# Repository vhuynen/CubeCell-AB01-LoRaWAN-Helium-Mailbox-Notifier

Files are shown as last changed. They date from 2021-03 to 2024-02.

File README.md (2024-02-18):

# HelTec-Cube-LoRaWAN-Helium-Mailbox-Notifier

The Mailbox Notifier is an IoT DIY project which notifies you each time you received a package or a letter in your letterbox. This is the same projet as the [ESP32-CAM-Mailbox-Notifier](https://github.com/vhuynen/ESP32-CAM-Mailbox-Notifier) one, but designed for long range distance.

This project uses an **HelTec AB01** LoRaWAN module to send data over an LoRaWAN Gateway when WiFi is out of range. I use an [Helium Gateway](https://www.helium.com/) from the **People's Network** in order to forward packets over Helium Network which sends data to [AWS IoT Core](https://aws.amazon.com/iot-core/) (MQTT) or [Pipedream](https://pipedream.com/) (HTTP) etc... LoRaWAN is a bidirectional protocol useful when you need to send few data over long distance (several miles) from low-power and low-bandwidth IoT.

The compromise over this kind of system is that you can't send heavy payload as you are able to do over WiFi. Finally the data must be treated over third-part system.

## Table of Contents

- [HelTec-Cube-LoRaWAN-Helium-Mailbox-Notifier](#heltec-cube-lorawan-helium-mailbox-notifier)
	- [Table of Contents](#table-of-contents)
	- [Architecture Schema](#architecture-schema)
	- [Helium Organization](#helium-organization)
		- [Registering the device in the blockchain](#registering-the-device-in-the-blockchain)
		- [Setting the AWS IoT Core Integration](#setting-the-aws-iot-core-integration)
		- [Decoder Function](#decoder-function)
		- [Flows](#flows)
	- [Telegram API](#telegram-api)
	- [Amazon Web Services](#amazon-web-services)
		- [AWS IoT Core](#aws-iot-core)
		- [Telegram Lambda Function](#telegram-lambda-function)
		- [Twilio Lambda Function](#twilio-lambda-function)
		- [Amazon SNS - Simple Notification Service](#amazon-sns---simple-notification-service)
		- [Rules](#rules)
	- [Heltec AB01](#heltec-ab01)
		- [Prerequisite](#prerequisite)
		- [Data Format](#data-format)
		- [First Byte values](#first-byte-values)
		- [Second and Third Byte](#second-and-third-byte)
		- [Power up](#power-up)
		- [Fetch mail](#fetch-mail)
		- [You have got mail](#you-have-got-mail)
		- [Power-Saving](#power-saving)
	- [Notifications in action](#notifications-in-action)
	- [Electic Schema](#electic-schema)

## Architecture Schema

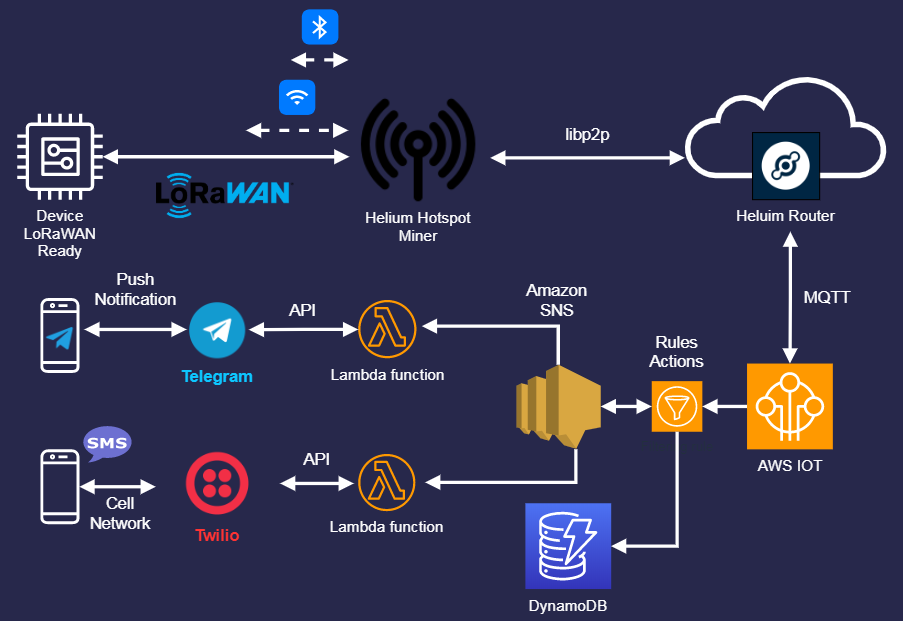
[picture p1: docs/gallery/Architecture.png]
architecture


## Helium Organization

Before going further, you should verify that you are within the coverage of the [Helium Network](https://explorer.helium.com/). Your device should be at the proximity of a least one gateway (350 meters). If not, this allows you to expand the network with your own gateway. After that, you will have to create an account on the [Helium Console](https://console.helium.com/).

### Registering the device in the blockchain

You must register your [device](https://docs.helium.com/use-the-network/console/adding-devices) in the blockchain. This operation can take a while (20 mins) before your device can join the network.
The registration generates three important values that you will have to report in the device's program later.

- **Device EUI** :
  - The DevEUI is a 64-bit globally-unique Extended Unique Identifier (EUI-64) generated throught the Helium Console. This identifier is mandatory because the Helium router has an XOR filter that filters packets from devices it knows only.
- **App EUI** :
  - the AppEUI is an application identifier, and this can be public without any concerns
- **App Key** :
  - The App Key is an AES-128 secret key that is shared between the device and your Helium Organization. This Key is used to provide end-to-end symmetric encryption of your payload data.

### Setting the AWS IoT Core Integration

Helium Console offers more than fifteen integrations and the list is constantly growing.
As expected in the architecture the payload data is forwarded to your AWS Organization. [You will have to connect your Helium Organization to your AWS Organization](https://docs.helium.com/use-the-network/console/integrations/aws-iot-core/).
In my case, the Uplink messages from Helium are published into a Topic named **topic/gateway**

### Decoder Function

[Function Decoder](https://docs.helium.com/use-the-network/console/functions/) is a JavaScript function that allows you to decode the byte payload into a readable JSON Format. The decoded payload is added to the main JSON payload that is forwarded to your Integration target. The payload will be entirely formatted into a [specific function](https://github.com/vhuynen/HelTec-AB01-LoRaWAN-Helium-Mailbox-Notifier/blob/main/source/decoder/MailboxNotifierDecoder.js) that transcodes the mailbox's state (which is hexadecimal) into a readable message enriched by the battery voltage and battery level.

``` js
function Decoder(bytes, port, uplink_info) {

	//decode message type form payload
	var data = bytes[0];
	//output decoded message depending on the data
	switch (data) {
		case 0x03:
			return {
				msg: "Uplink n°" + uplink_info.fcnt + "\n[OK] You have got mail !\nBattery Voltage: "
					+ ((bytes[1] << 8) + bytes[2]) / 1000
					+ " Volts\nBattery Level: "
					+ ((((((bytes[1] << 8) + bytes[2]) / 1000) - 3.7) / (4.2 - 3.7)) * 100).toPrecision(4)
					+ "%\nHave a nice day !",
					code : 03
			};
		case 0x02:
			return {
				msg: "Uplink n°" + uplink_info.fcnt + "\n[OK] You have got maybe a package !\nBattery Voltage: "
					+ ((bytes[1] << 8) + bytes[2]) / 1000
					+ " Volts\nBattery Level: "
					+ ((((((bytes[1] << 8) + bytes[2]) / 1000) - 3.7) / (4.2 - 3.7)) * 100).toPrecision(4)
					+ "%\nHave a nice day !",
			};
		case 0x04:
			return {
				msg: "[ERROR] Doors have been opened for too long since you have powered the device on."
					+ "\nReboot the device to reinitialize it !",
			};
		case 0x05:
			return {
				msg: "[ERROR] Doors have been opened for too long since you have fetched your mail."
					+ "\nReboot the device to re-initialize it !",
			};
		case 0x06:
			return {
				msg: "[ERROR] Doors have been opened for too long by the postman."
					+ "\nReboot the device to reinitialize it !",
			};
		case 0x01:
			return {
				msg: "Uplink n°" + uplink_info.fcnt + "\nYou have joined the people's network !\nBattery Voltage: "
					+ ((bytes[1] << 8) + bytes[2]) / 1000
					+ " Volts\nBattery Level: "
					+ ((((((bytes[1] << 8) + bytes[2]) / 1000) - 3.7) / (4.2 - 3.7)) * 100).toPrecision(4)
					+ "%\nHave a nice day !",
			};
		default:
			return { msg: "\nunknown" };
	}
}
```

### Flows

[Flows](https://docs.helium.com/use-the-network/console/flows/) is a powerful visual-centric view that allows users to instantly understand the relationship among devices, functions, and integrations. Flows enables users to visually connect nodes and control the data flow.
Right below, the basic flow used as part of the mailbox project :

Flow

## Telegram API

First, you will have to create your bot thanks to the [BotFather](https:telegram.me/botfather). Side note: there's no need to describe how to do that, there is solid content about this topic on the Web.

Keep carefully your **API Key** and your **Chat ID**, they will be required to set the AWS Lambda function later.

## Amazon Web Services

### AWS IoT Core

When a device joins the Helium Network for the first time, it's immediately attached to an **AWT IoT Core** Integration. Then the device is auto-provisionned by the API (Things, Certificat, Policy). The **name** of the ```Things``` is the same as the **ID** from the Devices Helium Console.

### Telegram Lambda Function

You now must create a Python Lambda function to send your message to your Telegram **Bot**. I have already written an article on how to do that : [Send Telegram Bot with Python and AWS Lambda](https://github.com/vhuynen/Telegram-Lambda-AWS-Python#readme).

You must declare two environment variables to set your Telegram lambda with the values previously retrieved from BotFather :

- _TELEGRAM_CHAT_ID_ : **\<Chat ID\>**
- _TELEGRAM_TOKEN_ : **bot\<API Key\>**

Below, the Python code to send message over Telegram for my Mailbox project :

``` python
import json
import os
import requests

TELEGRAM_TOKEN =os.environ.get("TELEGRAM_TOKEN")
TELEGRAM_CHAT_ID=os.environ.get("TELEGRAM_CHAT_ID")

def lambda_handler(event, context):
    
    sns_msg = event['Records'][0]['Sns']['Message']; 
    telegram_msg = sns_msg.replace("[ERROR]", "\u26A0").replace("[OK]", "\U0001F4EC"); # Mailbox Project

    bot_request = 'https://api.telegram.org/' + TELEGRAM_TOKEN + '/sendMessage?chat_id=' + TELEGRAM_CHAT_ID + '&text=' + telegram_msg
    print(event)
    print(bot_request)
    response = requests.get(bot_request) 
    return {
        'statusCode': response.status_code,
      'msg': json.dumps('Message send with successed !'),
       'body': json.dumps(response.json())
  }
```

### Twilio Lambda Function

(Optional): As for Telegram, you will have to create a Python Lambda in order to send SMS through Twilio. You can find an exemple of a code's snippet [here](https://github.com/vhuynen/Telegram-Lambda-AWS-Python#other-snippet).

### Amazon SNS - Simple Notification Service

The SNS is a Topic that once it receives any message, transfers it to all subscribers. In my case, the SNS calls both the Telegram Lambda endpoint as well as the Twilio Lambda endpoint. Now, create an SNS and connect the subscription's endpoints (Lambda) to it as well as policies in order to enable the SNS to call the Lambda functions.

### Rules

In order to treat the data from your device to AWS IoT Core, you must create a **Rules** that identifies your device thanks to a **filter**.
In my case, the filter selects the decoded message received from Helium and retreived from the **MQTT Topic** ```'topic/gateway'```. Finally, I applied the filter only on my **dev_eui** device.

Below, my [AWS IoT SQL](https://docs.aws.amazon.com/iot/latest/developerguide/iot-sql-reference.html) request:

``` sql
SELECT VALUE decoded.payload.msg FROM 'topic/gateway' where dev_eui = '6078F99C6925AD54'
```

To finish, select the SNS Push Notification previously created, choose the message format **RAW** and apply an IAM Role to grant the IoT Core to have access it.

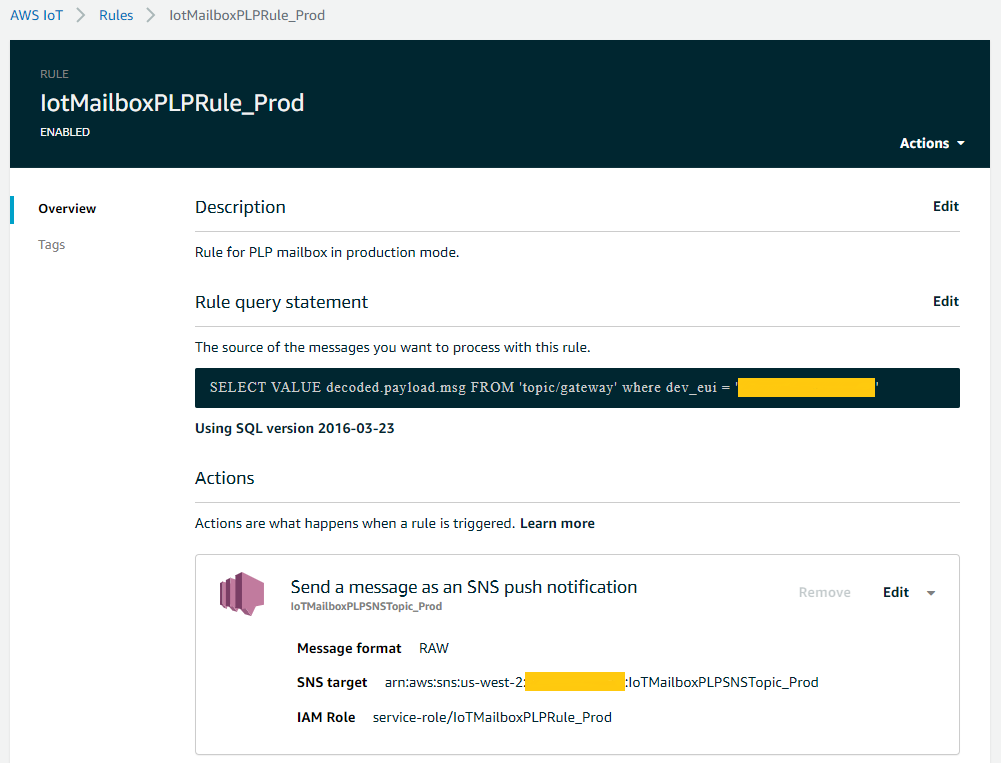
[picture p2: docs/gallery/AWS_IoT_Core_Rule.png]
Rule


Below, the hierarchical view of the AWS components involved:

``` text
AWS IoT Core
     └── Rules
           └── SNS Topic
                  ├── Telegram Lambda
                  └── Twilio Lambda
```

## [Heltec AB01](https://heltec.org/project/htcc-ab01/) 

### Prerequisite

> Before we begin, I **advise** you to read attentively this [post](https://docs.helium.com/use-the-network/devices/development/heltec/cubecell-dev-board/platformio/). Indeed, some settings need to be set to be suitable with the Helium Network. If you do not, you will have some issues to join the network.

Before to upload the program into the device, you must set your own **devEui**, **appEui** and **appKey** properties retreived from the Helium Console before.

Finally, set correctly your project configuration file [platformio.ini](https://github.com/helium/longfi-platformio/blob/master/Heltec-CubeCell-Board/examples/cubecell-helium-us915-basic/platformio.ini) to be compatible with your region frequency and more.

### Data Format

The data payload is structured in two parts :

- One Byte for the mailbox state
- Two Byte for the battery voltage

| First Byte|Second Byte | Third Byte|
|:---|:---|:---|
| State Mailbox|Battery Voltage|Battery Voltage
|[Hexadecimal value](https://www.thethingsnetwork.org/docs/devices/bytes/#what-the-hex)|Hight Byte [word](https://www.thethingsnetwork.org/docs/devices/bytes/#3-use-words) |Low Byte [word](https://www.thethingsnetwork.org/docs/devices/bytes/#3-use-words)

### First Byte values

Below the detail of the possible values for the first Byte:

| State Mailbox| Comments| Statut | LoRaWan Port|
| :---: |:---|:---:|:---:|
| 0x01|You have powered up the MCU, all doors are closed and the device has joined the Helium Network|OK|1|
| 0x02|The main door has been opened, you have received a package|OK|1|
| 0x03|The flip door has been opened, you have received some letters|OK|1|
| 0x04|You have left the doors opened for too long during cycle of power up|ERROR|2|
| 0x05|You fetched your mail and you have left the door open|ERROR|2|
| 0x06|The postman has left one door opened|ERROR|2|

### Second and Third Byte

The battery voltage is encoded with two Byte thanks to the [word](https://www.arduino.cc/reference/en/language/variables/data-types/word/) data type.

MCU side the battery voltage is **encoded** as is:

``` c
  int batteryVoltage = getBatteryVoltage();
  appData[1] = highByte(batteryVoltage);
  appData[2] = lowByte(batteryVoltage);
```

Below, the Helium JavaScript code that decodes the data of the battery voltage:

``` javascript
((bytes[1]  << 8 ) + bytes[2])  /  1000
```

### Power up

When you power up the device, you have 20 seconds to close all doors else you will receive an error message.
If everything is OK, then you will receive a message telling you that the device has joined the Helium Network.
If you did not receive it, then something has to be fixed. Check the incoming message from the real time packets view from the Helium Console... At this point, issues can be multiple.

### Fetch mail

You probably do not want to receive notifications while you fetch your mail. For this purpose, you will have to keep open the flip door and simultaneously open the main door. After that, you can close the flip door and take your mail. If the door remains open after 20 seconds you will receive an error message.

### You have got mail

The delivery man or the postman comes and opens one door then you will receive a notification. If the door remains open after 20 seconds then you will receive an error message.

### Power-Saving

The program uses Deep Sleep mode in order to widely reduce power consumption between each interrupt. Interrupts are triggered by the reed switches, if the signal is falling then the MCU wakes up and performs the loop.
The solar panel is not necessary, a LiPo battery 18650 with a capacity of 3000mAh can last at least two years. Moreover, you can follow the battery level and forecast the recharge.  

## Notifications in action

|Telegram Notification|SMS Twilio Notification|
|:---:|:---:|
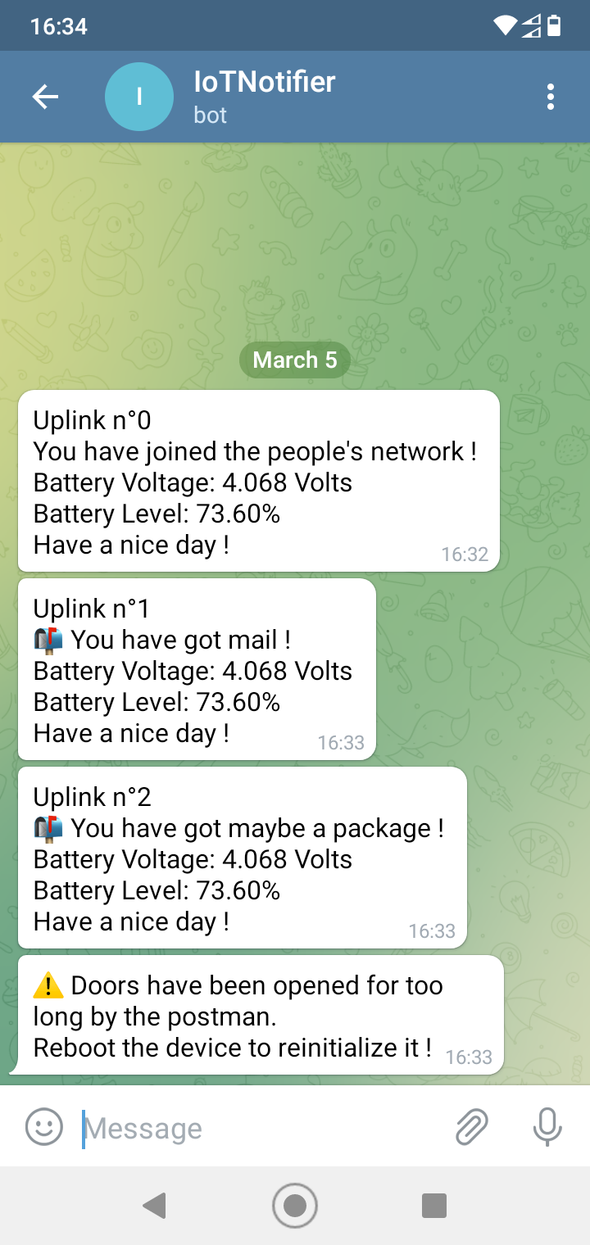
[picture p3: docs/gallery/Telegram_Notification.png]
Telegram
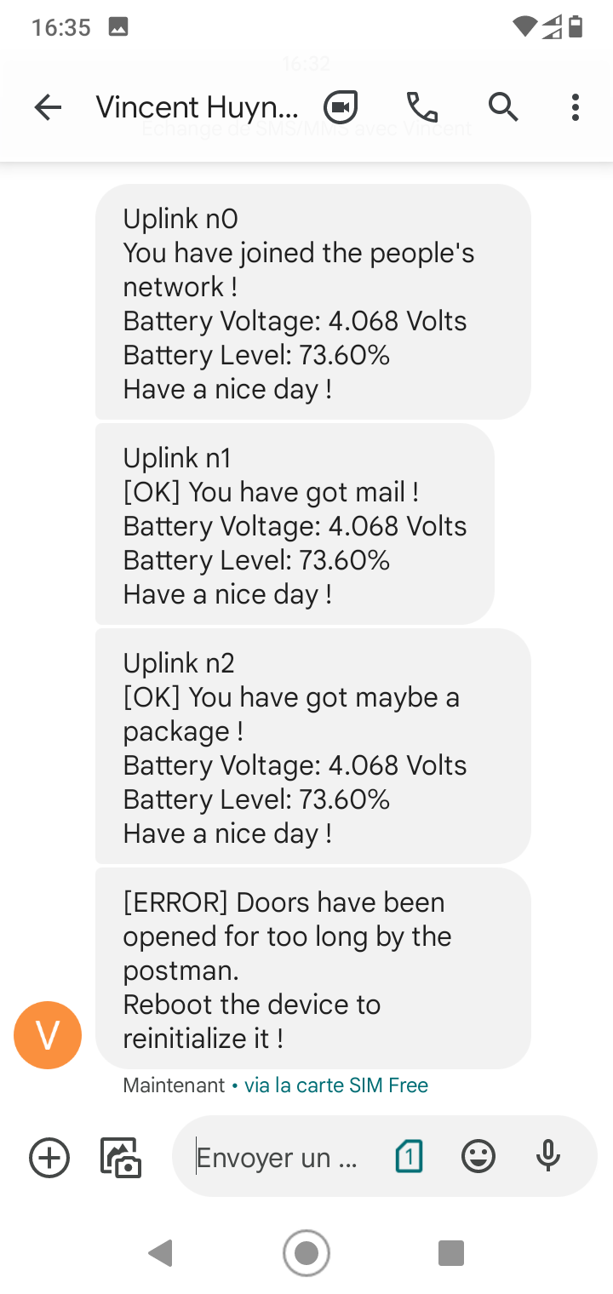
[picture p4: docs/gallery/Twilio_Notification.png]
Twilio
|||

## Electic Schema

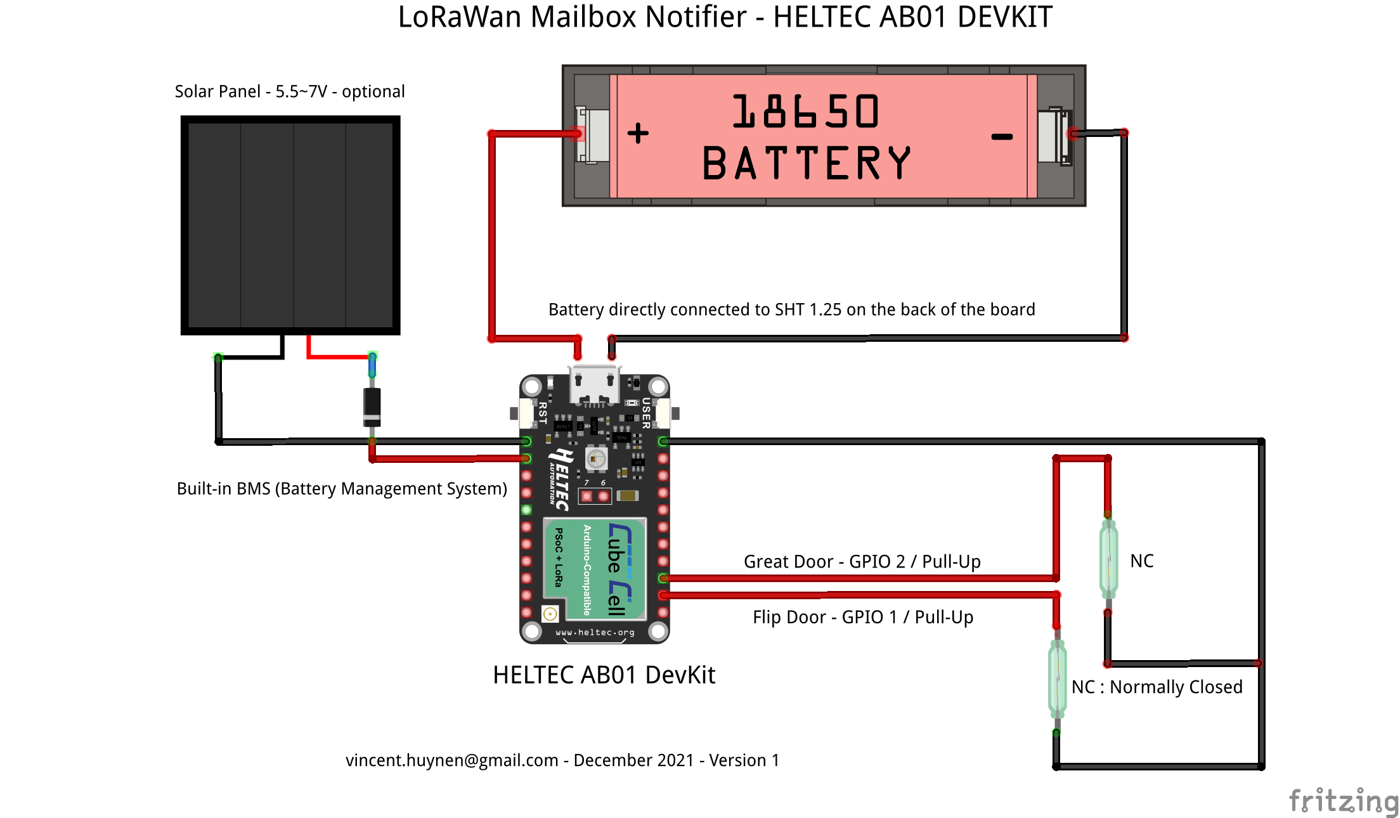
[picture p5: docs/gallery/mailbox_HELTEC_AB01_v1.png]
Electic Schema


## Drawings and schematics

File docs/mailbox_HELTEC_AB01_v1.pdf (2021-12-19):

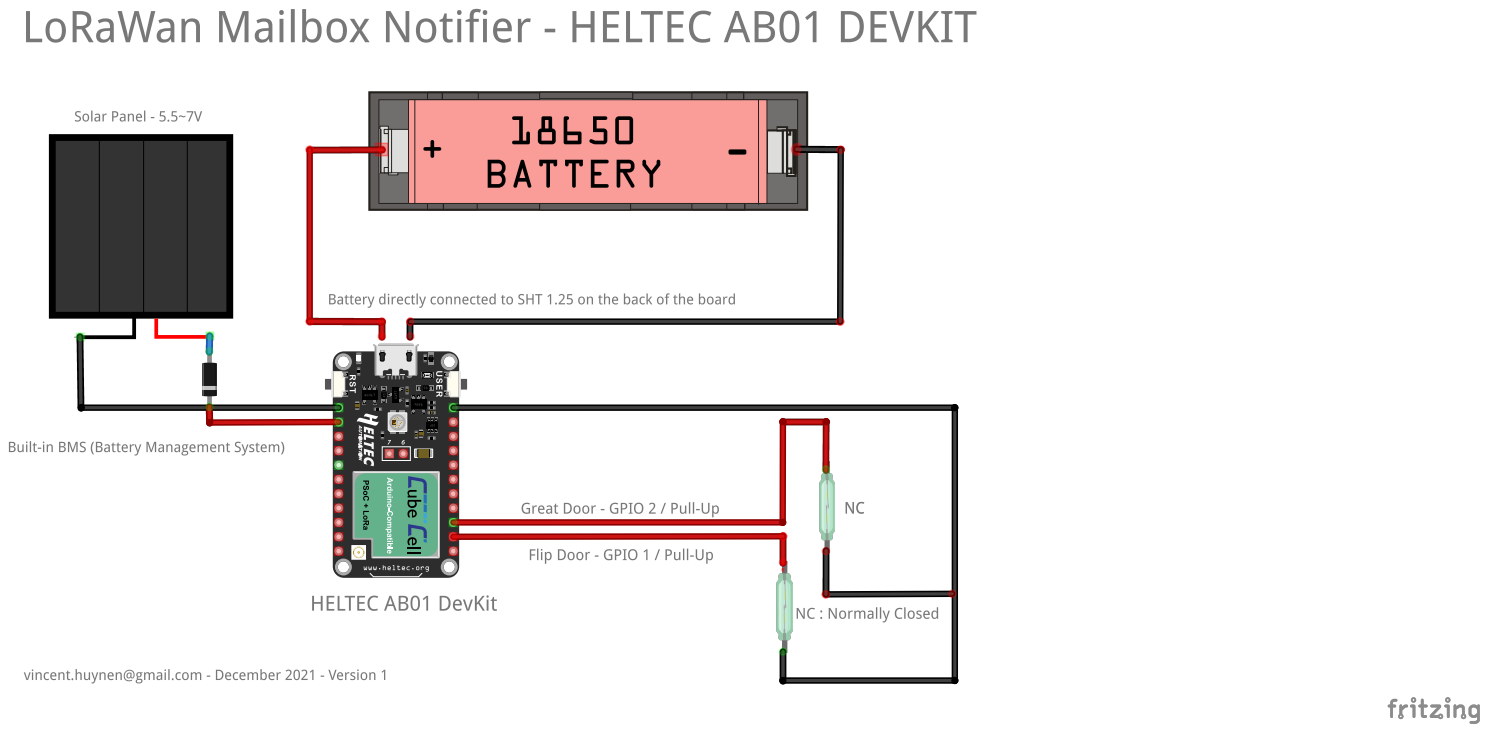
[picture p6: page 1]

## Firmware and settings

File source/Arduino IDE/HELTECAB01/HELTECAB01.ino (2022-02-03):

//####################### Vincent Huynen #######################/
//################## vincent.huynen@gmail.com ##################/
//######################### JANUARY 2022 ######################/
//#################### CubeCell HELTEC AB01 ####################/
//######################## Version 1.0.0 #######################/

/*
  LoRaWan Mailbox Notifier
*/

#include "Arduino.h"
#include "LoRaWanMinimal_APP.h"

/* OTAA settings from HELIUM Network*/
uint8_t devEui[] = {};
uint8_t appEui[] = {};
uint8_t appKey[] = {};

/* ABP para*/
uint8_t nwkSKey[] = {};
uint8_t appSKey[] = {};
uint32_t devAddr = (uint32_t)0x00;

int wake_count = 0;
int batteryVoltage, batteryLevel;

// Control properties
long overtime_open_door = 20000;

// Pin which handle the wake up
int pinFlipDoor = GPIO1;
int pinDoor = GPIO2;
int pinWakeUp = 0;
unsigned long currentMillis = 0;

uint8_t lowpower = 0;

bool ENABLE_SERIAL = false; // Enable serial debug output here if required
bool ENABLE_LORAWAN = true; // Disable LoRaWAN here in debug mode

/* LoRaWan settings */
uint16_t userChannelsMask[6] = {0x00FF, 0x0000, 0x0000, 0x0000, 0x0000, 0x0000};
LoRaMacRegion_t loraWanRegion = ACTIVE_REGION;
DeviceClass_t loraWanClass = LORAWAN_CLASS;
bool overTheAirActivation = LORAWAN_NETMODE;
bool loraWanAdr = LORAWAN_ADR;
//bool keepNet = LORAWAN_NET_RESERVE;
bool isTxConfirmed = LORAWAN_UPLINKMODE;
uint8_t appPort = 1;
uint8_t confirmedNbTrials = 4;
// Data Payload
uint8_t payload[3];



void onWakeUpByFlipDoor()
{
  lowpower = 0;
  pinWakeUp = pinFlipDoor;
  wake_count = wake_count + 1;
  detachInterrupt(pinFlipDoor);
  detachInterrupt(pinDoor);
  // Initialize current time
  currentMillis = millis();
  if (ENABLE_SERIAL)
  {
    Serial.println("WakeUp by the Flip Door");
  }
}

void onWakeUpByDoor()
{
  lowpower = 0;
  pinWakeUp = pinDoor;
  wake_count = wake_count + 1;
  detachInterrupt(pinFlipDoor);
  detachInterrupt(pinDoor);
  // Initialize current time
  currentMillis = millis();
  if (ENABLE_SERIAL)
  {
    Serial.println("WakeUp by the Door");
  }
}

void setup()
{
  if (ENABLE_SERIAL)
  {
    Serial.begin(115200);
  }
  // Initialize interrupt flip door's GPIO
  pinMode(GPIO1, INPUT_PULLUP);
  // Init interrupt door's GPIO
  pinMode(GPIO2, INPUT_PULLUP);
  // Initialize current time
  currentMillis = millis();
}

void loop()
{
  // Handling low power mode
  if (lowpower)
  {
    if (ENABLE_SERIAL)
    {
      Serial.println("Go to sleep! Zzzz");
    }
    lowPowerHandler();
  }

  if (!lowpower)
  {
    // When you turn on the controller a first time
    if (wake_count == 0)
    {
      if (digitalRead(pinDoor) == 1 && digitalRead(pinFlipDoor) == 1)
      {
        if (ENABLE_LORAWAN)
        {
          joinHeliumNetwork();
          compoundTxFrame(0x01, true);
          LoRaWAN.send(3, payload, 1, false);
        }
        // Only if all doors are closed
        if (ENABLE_SERIAL)
        {
          Serial.println("All doors are closed");
        }
        goToDeepSleep();
      }
      else if (millis() > overtime_open_door)
      {
        if (ENABLE_SERIAL)
        {
          Serial.println("Doors have been opened too long when you have turned on the MCU.\nReboot the MCU to reinitialize it !");
        }
        if (ENABLE_LORAWAN)
        {
          joinHeliumNetwork();
          compoundTxFrame(0x04, false);
          LoRaWAN.send(1, payload, 2, false);
        }
        goToDeepSleepError();
      }
    }

    // Ignore wake up when you fetch your mail, open the flip door first before opening the main door
    if (pinWakeUp == pinFlipDoor)
    {
      if (digitalRead(pinDoor) == 0)
      {
        while (digitalRead(pinDoor) == 0 || digitalRead(pinFlipDoor) == 0)
        {
          if (millis() > currentMillis + overtime_open_door)
          {
            if (ENABLE_SERIAL)
            {
              Serial.println("Doors have been opened too long time when you have fetched your mail.\nReboot the MCU for reinitialize it !");
            }
            if (ENABLE_LORAWAN)
            {
              compoundTxFrame(0x05, false);
              LoRaWAN.send(1, payload, 2, false);
            }
            goToDeepSleepError();
            break;
          }
        }
        if (!lowpower)
        {
          // Everythings is OK, you can sleep quietly
          if (ENABLE_SERIAL)
          {
            Serial.println("Everythings is OK, you can sleep quietly");
          }
          goToDeepSleep();
        }
      }
    }
    // You have got mail ! Let's go...
    if (pinWakeUp == pinDoor || pinWakeUp == pinFlipDoor)
    {
      if (digitalRead(pinDoor) == 1 && digitalRead(pinFlipDoor) == 1)
      {
        if (pinWakeUp == pinDoor)
        {
          if (ENABLE_SERIAL)
          {
            Serial.println("You have received a parcel !");
          }
          if (ENABLE_LORAWAN)
          {
            compoundTxFrame(0x02, false);
            LoRaWAN.send(3, payload, 1, false);
          }
        }
        if (pinWakeUp == pinFlipDoor)
        {
          if (ENABLE_SERIAL)
          {
            Serial.println("You have received a letter !");
          }
          if (ENABLE_LORAWAN)
          {
            compoundTxFrame(0x03, true);
            LoRaWAN.send(3, payload, 1, false);
          }
        }
        // Everythings is OK, you can sleep quietly
        goToDeepSleep();
      }
      if (millis() > currentMillis + overtime_open_door)
      {
        // Send error
        if (ENABLE_SERIAL)
        {
          Serial.println("Doors have been opened too long time by the postman.\nReboot the MCU for reinitialize it !");
        }
        if (ENABLE_LORAWAN)
        {
          compoundTxFrame(0x06, false);
          LoRaWAN.send(1, payload, 2, false);
        }
        // Something wrong, going to sleep until reset or restart
        goToDeepSleepError();
      }
    }
  }
}

// Deep Sleep when everythings is right
void goToDeepSleep()
{
  if (ENABLE_SERIAL)
  {
    Serial.println("Going to sleep...");
  }
  // Prepare settings before going to sleep
  attachInterrupt(pinFlipDoor, onWakeUpByFlipDoor, FALLING);
  attachInterrupt(pinDoor, onWakeUpByDoor, FALLING);
  pinWakeUp = 0;
  // Go to sleep! Zzzz
  lowpower = 1;
}

// Deep Sleep when something's wrong
void goToDeepSleepError()
{
  if (ENABLE_SERIAL)
  {
    Serial.println("Going to sleep because something's wrong...");
  }
  // Prepare settings before going to sleep
  pinWakeUp = 0;
  // Go to sleep! Zzzz
  lowpower = 1;
}

// Join the Helium Network
void joinHeliumNetwork()
{
  // Initialize LaRaWAN settings
  LoRaWAN.begin(LORAWAN_CLASS, ACTIVE_REGION);

  // Enable ADR
  LoRaWAN.setAdaptiveDR(true);
  // Set Fixed Data Rate
  //LoRaWAN.setFixedDR(0);

  while (1)
  {
    if (ENABLE_SERIAL)
    {
      Serial.print("JOINING... ");
    }
    LoRaWAN.joinOTAA(appEui, appKey, devEui);
    if (!LoRaWAN.isJoined())
    {
      if (ENABLE_SERIAL)
      {
        Serial.println("JOIN FAILED!");
      }
    }
    else
    {
      if (ENABLE_SERIAL)
      {
        Serial.println("JOINED");
      }
      break;
    }
  }
}

/* Prepares the payload of the frame */
void compoundTxFrame(char state, boolean setVoltage)
{
  payload[0] = state;
  if (setVoltage)
  {
    batteryVoltage = getBatteryVoltage();
    if (ENABLE_SERIAL)
    {
      Serial.println("Voltage in mV: " + batteryVoltage);
    }
    payload[1] = highByte(batteryVoltage);
    payload[2] = lowByte(batteryVoltage);
  }
}

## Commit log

2021-12-15 Add root repository for IDE Arduino
2021-12-17 Sending battery voltage and adding a specific LoRaWan API for this purpose.
2021-12-19 Adding of the electronic schema
    [mailbox_HELTEC_AB01_v1.fzz]
2022-08-16 Fix issue with interrupts handled by a reed switch.
    /!\ In order to avoid bounces with the reed switch, you must stop the MCU a while.
    /!\ The delay function fixes the electrical noise generated by the reed switch.
    [HELTECAB01.cpp]
